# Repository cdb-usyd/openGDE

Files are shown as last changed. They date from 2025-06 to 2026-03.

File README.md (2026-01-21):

# openGDE
An open-source electrochemical test platform. Published in the Australian Journal of Chemistry. Manuscript DOI: [10.1071/CH25175](https://doi.org/10.1071/CH25175)

Repository release v1.0.0 available: 

## Information
- Designed in [openSCAD](https://openscad.org/), with code written as extensibly as possible for people to adapt for their needs.
- STLs sliced using [CURA](https://ultimaker.com/software/ultimaker-cura/) 4.12.1 or [OrcaSlicer](https://www.orcaslicer.com/) 2.3.1
- Printed on a modified Ender 3 (running [Octoprint](https://octoprint.org/) 1.9.3, all metal hot-end and glass bed for most prints).
- Printed with PLA, PETG, TPU, TPE.

## Additional hardware
- M3 nuts and bolts (12 mm).
- Standard nylon tube for pneumatic applications, 4mm OD with 2.5mm ID (cut to length and flattened with heat treatment and mold).
- Commercial membrane (tested with Nafion and Fumasep FAD)

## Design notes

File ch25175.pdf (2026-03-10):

RESEARCH PAPER

https://doi.org/10.1071/CH25175

openGDE/bayadjamara: an open-source 3D-printable gas diffusion electrochemical reactor platform

Christopher BarnettA,B,C,* | , Alexander K. L. YuenA,B | , Anthony F. MastersA | and
Thomas MaschmeyerA,B,C,*

ABSTRACT

We introduce a flexible reactor platform for testing electrocatalysts, especially for gas-phase reactants or products. This open-source, 3D-printable platform has been designed for gaseous reagents in general and is readily modified to suit a range of applications, configurations and reactor sizes. We demonstrate the versatility of our platform with iridium(IV) oxide as a standard catalyst for water splitting, using a range of conditions that relate the system’s performance to the literature. To encourage adoption of our system, we have included detailed build instructions, 3D-printing tips, example reactor configurations and a guide on modifying the provided design code. It is our hope that the simplicity, low-cost and provision of design files will encourage use of the system to more easily enable appropriate testing of gas-diffusion electrocatalysts that will allow for ready cross-laboratory comparison and benchmarking.

Keywords: 3D printing, additive manufacturing, electrocatalysis, electrochemistry, gas diffusion electrode, labware, reactor design.

Introduction
Reliable data is the cornerstone of good science. The performance of different gas diffusion electrode (GDE) catalysts must be compared using data generated from an appropriate system.¹,2 This requires well-defined electrodes and precise reactor geometry that can be easily reproduced, and most importantly, a gas diffusion setup. Despite general agreement on these requirements, the performance of catalysts proposed for use in a GDE is still mostly evaluated using standard aqueous three-electrode setups,³⁻⁵ with the gas of choice simply bubbled through the solution. There are three significant drawbacks with this approach: first, this is not a gas diffusion electrode, second, most gases have a low solubility in solution (see Solubility of Gases in Water vs. Temperature at https://www.engineeringtoolbox.com/gases-solubility-water-d_1148.html), third, the observation that often catalysts behave differently when operating in gas-in-solution systems versus pure gas or reactant-in-gas systems.¹,2,6,7
GDEs are becoming increasingly popular research platforms, with applications in: reverse fuel cells,⁶,8–13 waste remediation¹⁴ and electrolysis,¹³ as well as any electrochemical reaction where a reagent or product is a gas or is contained in a gas stream, such as CH4,

15 CO2

16–18 and CO.⁶
It has been firmly established that testing of GDE catalysts in a three-electrode setup can significantly skew the observed performance.⁶,7 The performance estimates can be skewed either too low, thereby leading to the premature exclusion of promising catalyst candidates, or too high, thereby encouraging unprofitable further research.¹,19
A case in point is that of the translation of laboratory results into commercial hydrogen fuel cells.²⁰ Even when restricting the scope to just that of platinum-based oxygen reduction reaction (ORR) catalysts, markedly different performance in liquid half-cells as compared to commercially relevant GDE-based fuel cells²¹,22 has been reported for e.g. Pt-alloys,²³ de-alloyed Pt–Ni nanoparticles¹⁹,24 and Pt–Ni nanoframes.²⁵,26 To address

For full list of author affiliations and declarations see end of paper

*Correspondence to:
Christopher Barnett
The Laboratory of Advanced Catalysis for Sustainability, The University of Sydney, Sydney, NSW, Australia
Email: christopher.barnett@sydney.edu.au

Thomas Maschmeyer
The Laboratory of Advanced Catalysis for Sustainability, The University of Sydney, Sydney, NSW, Australia
Email: thomas.maschmeyer@sydney.edu.au

Handling Editor:
Paul Bernhardt

Received: 5 November 2025
Accepted: 19 January 2026
Published: 24 February 2026

Cite this: Barnett C et al. (2026) openGDE/ bayadjamara: an open-source 3D-printable gas diffusion electrochemical reactor platform. Australian Journal of Chemistry 79, CH25175. doi:10.1071/CH25175 (https://doi.org/10.1071/CH25175)

© 2026 The Author(s) (or their employer(s)). Published by CSIRO Publishing.
This is an open access article distributed under the Creative Commons Attribution 4.0 International License (CC BY) (https://creativecommons.org/licenses/by/4.0/)

OPEN ACCESS

Downloaded from http://connectsci.au/ch/article-pdf/doi/10.1071/CH25175/1858128/ch25175.pdf by guest on 10 March 2026

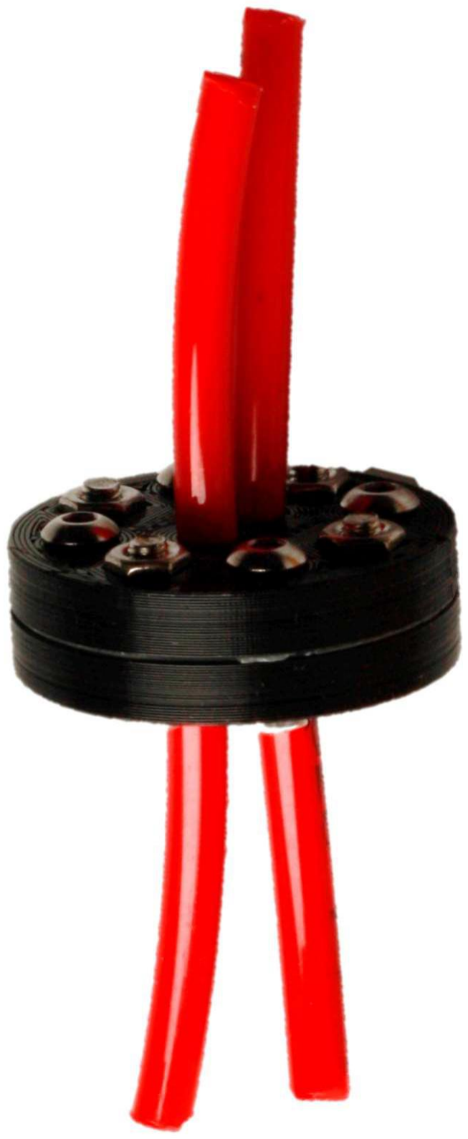
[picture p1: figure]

these inconsistencies, several calls have been made for the standardisation of candidate catalyst testing within GDE or membrane electrode assembly (MEA) setups.⁶,21,22 Although commercial GDE test reactors are available, they are expensive, non-standardised and somewhat limited in scope or adaptability. By contrast, a liquid-based three-electrode setup requires nothing more than a beaker as the reactor; though testing should ideally be performed with the working electrode (WE) and counter electrode (CE) separated, such as in U-tube cells⁴,27,28 and H-cells.²⁹ With the rise in additive manufacturing, there has been an increase in the number of reports of 3D-printed GDE reactors.¹,30,31 However, these publications often provide insufficient detail to reproduce the reactor, and we are unaware of any that provide access to the design files.
Notably, there is no agreed upon standard GDE reactor. Instead, the common practice is to compare the performance of a new catalyst against that of a ‘standard’ or benchmark catalyst, within the same reactor.³² This practice is problematic when no standard catalyst exists for a reaction, such as carbon dioxide reduction,³³ nitrogen reduction³⁴ and the dehydrogenation of ethylbenzene.³⁵ This practice also relies on reproducible benchmark catalysts to be accessible to all researchers, and for the reactor design to not mask the catalyst performance due to mass diffusion limitations or temperature gradients.³⁶
It has been elegantly shown by Ehelebe et al. that the specific GDE reactor set-up (i.e. size, shape, orientation of the gas flow field) is less important for reliable catalyst testing than reproducible sample preparation (e.g. ensuring homogeneity and representative of the bulk) and the electrochemical protocols (e.g. not diffusion limited, appropriately referenced) used.³⁷ However, these protocols rely on having a means to establish, for example, the electrochemically active surface area; a problem for newly synthesised materials or unestablished reactions. Most importantly, access to a GDE/ MEA test reactor is a pre-requisite for analysis of gas-phase electrochemistry. In these circumstances, access to a standardised reactor would allow for meaningful comparisons of catalyst performances.
To address these issues, we have developed an accessible, affordable and adaptable 3D-printed GDE/MEA test reactor: ‘openGDE’ or ‘bayadjamara’.A We provide the design files and detailed instructions on how to modify and print the reactor platform, suitable for even a relatively novice operator. 3D-printing offers adaptable design, access to unique geometries not available through traditional subtractive manufacturing, and importantly, easy fabrication of multiple reactors, which drastically lowers the cost of GDE/MEA test reactors and allows for parallel testing.
For reactions with established catalysts or electrochemical protocols,³⁷ we are confident that openGDE will facilitate comparison with existing data. This research platform is designed to encourage appropriate testing of GDE/MEA catalysts by the user community to enable and enhance research quality and outcomes, i.e. testing and comparisons of catalysts under near identical and well-specified conditions – analogous to the improvements in the field of zeolite catalysis that have arisen from the introduction of a standard, verified zeolite preparation and characterisation methods.³⁸
To achieve this end, we set out to:
1. improve the accessibility of GDE reactors for research;
2. design the GDE reactor in a way that is easily adaptable to fit a variety of needs;
3. develop a platform for 3D-printable reactors, rather than a one-off design;
4. to make printing possible on even hobbyist-grade 3D printers with readily available filaments; and
5. to simplify the design and printing process to enable confident comparisons of GDE catalysts between different laboratories.
Two configurations of our 3D-printable GDE reactor for catalyst evaluation are shown in Fig. 1 and 2, with the adaptable source files being released open-source. Both the model files (.STL and .3MF) of the components used in this work, as well as the design file (.SCAD) are available on both Github and Zenodo, which also includes instructions on how to use the ‘Customizer’ feature to modify the reactor to the required parameters (see ‘Component variables’ in the Supplementary material). Additionally, a list of common 3D-printing terminology is provided in the Table S5 of the Supplementary material.

Copper
current
collector

GDE1

GDE2

Gas

Pseudo-reference

Membrane

Gas

Gasket

Gasket

GDE chamber

Fig. 1. Left: image of example GDE|GDE reactor, using default settings (e.g. GDE 1 cm²
). Right: simplified schematic of the reactor design.

ABayadjamara means ‘air maker’ in Gadi language and has been suggested as an appropriate name by Prof. Jakelin Troy, Director, Indigenous Research, Professor of Anthropology at The University of Sydney.

C. Barnett et al. | Australian Journal of Chemistry 79 (2026) CH25175

Downloaded from http://connectsci.au/ch/article-pdf/doi/10.1071/CH25175/1858128/ch25175.pdf by guest on 10 March 2026

Experimental
Detailed printing instructions, including tips and tricks for achieving best print results, are included in the ‘3D printing instructions’, ‘3D-printing Workflow’ and ‘Specific instructions for the main components’ sections in the Supplementary material. The reactors used for this work were printed using the settings summarised in Table 1. The printing instructions included in the ‘GDE’ and ‘Aq’ setions in the Supplementary material were followed by three other researchers, who each successfully assembled openGDE. Five different printers (see ‘Printers tested’ in the Supplementary material) were also used to print operational reactors.
Bolt tightness was tested using a Vevor torque screwdriver, with the inch–pound scale converted to Newton metres. The maximum practical pressure achievable was tested using a variation of the GDE|GDE setup of openGDE. Resin held up to 4 barg, and for fused deposition modelling (FDM) between 2.5 barg (untreated) and 3.5 barg (vapour smoothed), with additional details available in the ‘Good seals’ and ‘Gasket’ sections in the Supplementary material.
To ensure consistency, multiples of each iteration of a design were printed at the one time with the same settings and filament source for each component. A bed of 16 GDE chambers on conservative print speeds is easily achieved in a single 9-h (overnight) print. The design files include the option to add a label or identifier, placed in areas that minimally affect performance, to aid in the tracking of which components were used within a given experiment.

Discussion
In 2008, the first self-replicating 3D printer, the RepRap, produced its first child printer.³⁹ This achievement, as well

GDE

Gas

Pseudo-reference

Counter electrode Aqueous chamber

Working
electrode
wire

Copper
current
collector | GDE chamber

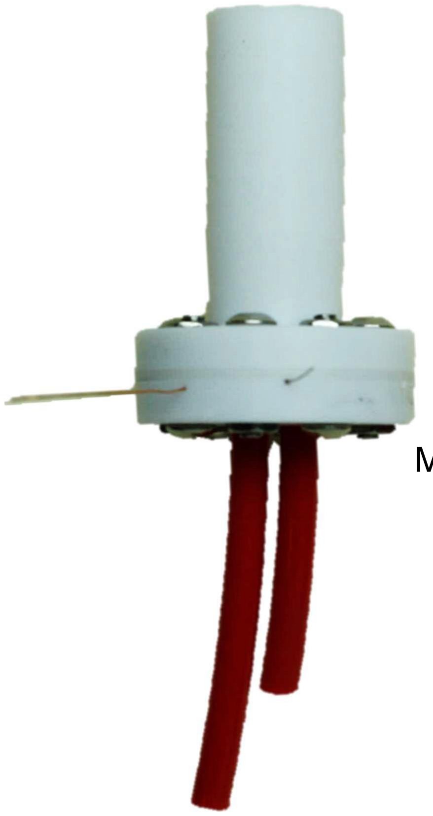
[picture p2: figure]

Membrane

Gasket

Gasket

Fig. 2. Left: image of an example GDE|Aq reactor, using default settings (e.g. GDE 1 cm²
). Right: simplified schematic of the reactor design.

Table 1. Common filament comparison.

Filament | ABS | HIPS | PETG | PLA | PP | TPE | TPU | SLA
Cost | $$ | $ | $$ | $ | $$$ | $$$ | $$ | $
Rigidity | HS | MS | HS | HS | SF | VF | F | V
Elasticity | LE | ME | M-HE | M-HE | HE | HE | HE | V
Bowden | Y | Y | Y | Y | OK | D | D | NA
H2SO4 | E | E | E | E | E | P | E | E
KOH | E | E | P | E | E | P | P | E
Na2SO4 | E | E | E | E | E | E | E | E
H2O | E | E | E | E | E | E | E | E
Nozzle (°C) | 190–210 | 230–245 | 235–245 | 210–225 | 235–245 | 235–245 | 228 | NA
Bed (°C) | 90 | 70 | 70 | 50 | 60 | NA | NA | NA A
Bed material | PEI/Glass B | PEI | Glass | Glass | PP tape | Glass | Glass | NA
Chamber | Yes | Yes | Yes | Opt. | Yes | Opt. | Opt. | Yes

Cost refers to the relative amount per kilogram from online retailers in Australia. Rigidity and Elasticity are: H (high), M (medium), L (low), S (stiff), F (flexible), E (elastic), V (varies with material. For example, SLA resins are sold with varying characteristics). The Bowden measure is whether the material is suitable to print with a Bowden extruder setup. Y (yes), OK (depends on tuning), D (difficult, not recommended for beginners). H2SO4, KOH, Na2SO4 and H2O concentrations were 0.1 M; E (excellent), P (poor) refer to how compatible the filament is with the listed solution. Bed is the recommended bed temperature during printing. Bed material is the recommended bed material. PEI (polyetherimide) and garolite are common bed materials available for purchase. Most packaging tapes are made of PP (polypropylene). Recommendations are limited to simple bed materials, not engineering grade. The Chamber measure is whether a chamber or enclosure is required for suitable prints. Opt. is optional, though a chamber is always recommended to contain the volatile components that are produced when printing. ABS, acrylonitrile butadiene styrene; HIPS, high-impact polystyrene; PETG, polyethylene terephthalate glycol; PLA, polylactic acid; TPE, thermoplastic elastomers; TPU, thermoplastic polyurethane; SLA, stereolithography. A
SLA/resin prints can fail at low ambient temperatures. B
A thin layer of ABS dissolved in acetone is applied to the surface and allowed to dry before printing.
www.publish.csiro.au/ch | Australian Journal of Chemistry 79 (2026) CH25175

Downloaded from http://connectsci.au/ch/article-pdf/doi/10.1071/CH25175/1858128/ch25175.pdf by guest on 10 March 2026 as the release of the printer designs under the free and open-source MIT license, started the additive manufacturing boom that has seen the release of hundreds of commercially available 3D printers – from DIY kits to fully assembled turnkey solutions. Over the years, through a combination of improved hardware, as well as advanced (including AIenhanced) software, the quality of printing has improved to the point of commercial products, including 3D-printed components. 3D-printing has become available to the masses, with the barrier to entry low enough that many printers are available that are plug-and-play and affordable (prices as of 6 January 2026), for example:
- US$179, Creality Ender-3 V3 SE (see https://store.creality.com/products/ender-3-v3-se-3d-printer). (https://store.creality.com/products/ender-3-v3-se-3d-printer)
- US$239, ELEGOO Neptune 4 pro (see https://us.elegoo.com/products/elegoo-neptune-4-pro-fdm-3d-printer) (https://us.elegoo.com/products/elegoo-neptune-4-pro-fdm-3d-printer)
- US$169, Anycubic Kobra 3 (see https://store.anycubic.com/products/anycubic-kobra-3). (https://store.anycubic.com/products/anycubic-kobra-3)
3D-printing has evolved beyond that of a tinkerer’s hobby – where maintenance and modification of the printer was the goal. Many 3D printers are now available as a ‘tool’, rather than a ‘project’. These printers are reliable and do not require intimate knowledge of how the machines work to achieve reliable prints. It is our hope that openGDE comes to fill the same niche, allowing researchers to 3D-print a reactor without having to delve deeply into computer aided design (CAD), while providing an open-source community to advance the platform.

Materials choice
Along with the advances in accessibility, the available materials for printing are becoming ever more numerous. Filaments are available with additives to control the printing and physical properties, as well as optional colourants added for surface finish and artistic purposes. In the context of openGDE, chemical compatibility with the solvents and reagents used is paramount. There is also the potential of contaminants in the filaments, such as metal particles,⁴⁰ or indeed constituents of the filament itself.
The final consideration is ease of printing. Although polyether ether ketone (PEEK) and polyether ketone ketone (PEKK) are both highly chemically resistant thermoplastics, they cannot be printed on a hobby 3D printer; as this requires advanced hot-ends that reach temperatures well above those achievable with such systems, and need an enclosed and actively heated chamber to avoid catastrophic warping and de-lamination. Even with these requirements met, the geometries and surface finishes achievable make it challenging to get a water-tight reactor with PEEK and PEKK.
The physical properties and chemical compatibility of several commercially available filament materials were tested for suitability for use in openGDE. The testing methodologies and details are available in the ‘Experimental details’ section of the Supplementary material, and the results are summarised in Table 1. PLA is recommended as the most suitable filament for the majority of applications due to its broad chemical resistance and ease of printing on most machines.

Dimensions and configurations of openGDE
openGDE is designed to be a testing platform, adaptable to many needs and requirements. For our experiments, we selected a GDE disc diameter of 11.2 mm, as this provides a membrane interface of 1.00 cm²
, simplifying calculations. For this size of disc, eight M3 bolts were ideal. If scaling up, larger bolts would provide a better seal; this is available in the customiser as a single bolt size variable. See the ‘Component variables’ section in the Supplementary material for more details on customising the openGDE, with examples.
There are numerous excellent papers that detail reactor configurations for various applications,³²,41,42 and an indepth discussion is beyond the scope of this paper. As well as adaptable dimensions, openGDE includes options for different configurations. Two thoroughly tested variants are discussed below.
A commonly reported setup is GDE|GDE, shown in Fig. 1, where both reactions are in the gas phase.¹,32,43 A MEA describes a membrane coated with a different catalyst on each side, and two gas flow fields.³² This MEA configuration is included in openGDE by use of a flow field insert printed from conductive filament, or a copper disc for edge contact, vide infra. However, for many GDE catalyst performance measurements, there is no need for the counter reaction to also be in the gas phase. A full GDE|GDE set-up represents an unnecessary complication when comparing GDE catalysts.²,36,37,44 We therefore designed an aqueous chamber for the counter reaction (Fig. 2). The authors are unaware of a commercial reactor that includes this set-up, could only find two examples of this concept within the literature,²,36,37 and note that no design files are provided to accompany those examples.
The openGDE aqueous chamber (Aq) is designed to provide simple assembly, with adequate access to the nuts and bolts, and the default sizing also allows for sufficient solution volume (3 mL) and membrane surface area (1 cm² ).
This setup provides reliable performance evaluation for the GDE catalyst,²,36 without the included complexity of managing two gas streams, particularly when the counter reaction has diffusion limitations or sluggish kinetics.³⁷ Complete instructions and guideline sizing limits are available in the ‘Some design choices/3D printing tricks’ and ‘Component variables’ sections of the Supplementary material.

Components of an electrochemical cell
The various methods to integrate the essential elements of an electrochemical cell into openGDE are briefly discussed here.

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

Gas flow
The default version of openGDE uses 4-mm outer diameter nylon tubing as the inlet and outlet. It was found most convenient to use a short section of tubing (5 cm) and connect to longer tubing as needed with pneumatic fittings. The tube end was heat-moulded, either against glass or a resin printed mould (see the ‘T-shaped tubes’ section in the Supplementary material for additional details).

Electrical
An electrical connection between the catalyst and the outside of the reactor was achieved by using an enamelled copper wire inserted through the reactor wall. This wire was then connected to an optional copper disc as current collector (see Fig. 3); removing the copper disc did not significantly affect the performance. Wire with a diameter of 0.2 mm was used, which has a current rating up to 200 mA, meaning that it is more than adequate for the testing included here (<10 mA).

Reference
Reference electrodes in a MEA or GDE setup are nontrivial. For our testing, we successfully implemented three set-ups:
1. The reactor can be run in symmetric mode, where the counter electrode is the reference electrode.
2. A pseudo-reference electrode is possible through insertion of either of a platinum wire or a silver-chloridecoated silver wire on the working electrode side of the membrane.
3. If the reactor is configured to include a liquid chamber, a standard reference (such as Ag/AgCl or Hg/HgO) can be used.

Membrane
Only commercial membranes have been tested in openGDE. They were sealed with the 3D-printed gasket, and the additional support provided by the bolts holds them in place.

Seals
The seals are very important to a functional reactor. Smooth mating surfaces and dimensionally matched gaskets are key for adequate sealing.

GDE/MEA
Depending on the configuration required, two methods of supporting the catalyst have been included here. The first uses a thick (0.5–2.0 mm) self-supporting carbon layer disc. The second, based on a thin gas diffusion layer (gdl), adds a flow field plate into the GDE half-reactor. The latter version is more complex, with either conductive filament or copper plating recommended for the flow field plate.

Aqueous
When using an aqueous chamber, it was found that prolonged exposure of one side of the membrane to an aqueous solution and to a comparatively dry gas on its other side could result in deformation of the membrane towards the aqueous side, eventually leading to a physical separation from the electrical contact with the GDE catalyst. A mesh

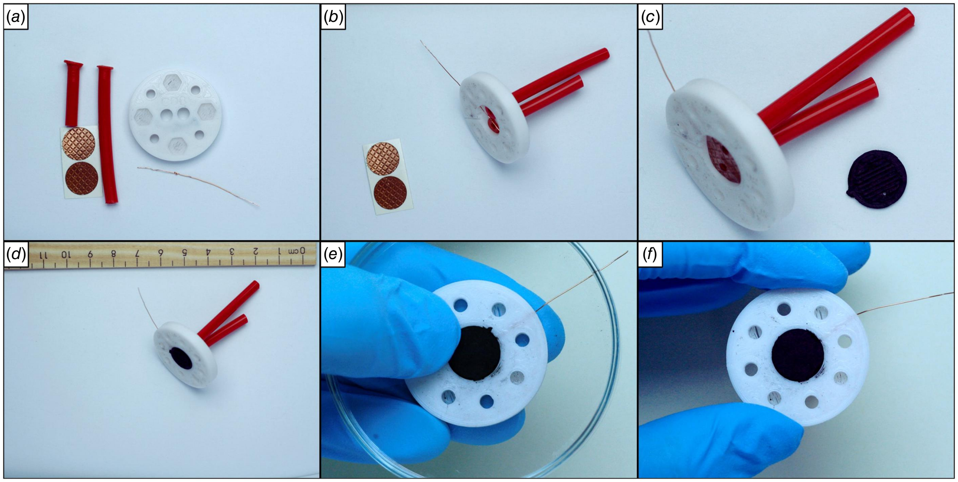
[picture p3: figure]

Fig. 3. Example assembly of a GDE sub-assembly, both the MEA and GDE versions. (a) Components needed: two T-shaped tubes, enamelled copper wire, 3D-printed GDE component (white PLA), and optional laser-cut copper tape. Not shown: gas diffusion layer (gdl) flow field insert (c, d) or GDE disc (e, f). (b) Gas tubing and enamelled wire installed. (c) Copper tape installed. Parallel flow field gdl insert shown next to component. (d) Assembled MEA half cell, with parallel gdl insert. Note the alignment pin. (e) A glass Petri dish being used to evenly insert a GDE disc into the reactor. (f) Assembled GDE sub-assembly.

Downloaded from http://connectsci.au/ch/article-pdf/doi/10.1071/CH25175/1858128/ch25175.pdf by guest on 10 March 2026 and a spacer insert were designed to hold the membrane in good contact with the GDE.

Assembly overview
The aim of openGDE is to provide an affordable and easy to construct testing platform. We therefore give a brief overview of the components needed (Fig. 4) and assembly steps involved with constructing openGDE. The Supplementary material includes more complete assembly instructions (‘Reactor assembly guides’ section), a cost breakdown (Table S3), and an example video of a reactor assembly (see CH25175_VideoS1.mkv).
The basic steps to assemble a GDE|Aq reactor are:
1. Gather M3 hardware and print the required half-reactors plus gaskets. Prepare the catalyst discs and activate chosen membrane.
2. Assemble GDE sub-assembly (Fig. 3). Insert tubing and electrical wires.
3. Prepare the gasket-membrane-gasket sandwich and pierce holes.
4. Insert catalyst disc and screw reactor together. Tighten just before use.

Electrochemistry
The capabilities of openGDE as a suitable reactor for a range of electrochemical conditions are demonstrated in Fig. 5. The experimentally simpler GDE|Aq reactor configuration was employed and printed using readily available PLA filament.
As mentioned above, there are three methods to include a reference in openGDE: (i) symmetric-mode, (ii) insertion of a pseudo-reference or (iii) use of a standard reference electrode (e.g. Ag/AgCl) in the counter reaction aqueous chamber. Each version has its advantages and disadvantages. Running a reactor in symmetric mode is commonly reported.³²,45,46 However, this requires a standardisation of the reactor using a benchmark catalyst to provide insight into the true over-potential of the reaction occurring at the working electrode. The potential of the counter reaction can vary over the course of a reaction, and the iR losses should be compensated to account for the membrane between the electrodes.³⁷ The success of the pseudo-reference method depends on the nature of the reaction taking place. Care needs to be taken to ensure that the pseudo-reference is not participating in the reaction and is not becoming fouled during the course of the experiment.⁴⁴ Finally, the use of a standard liquid reference is only possible when the counter reaction is in the liquid (using the Aq chamber); however, the iR losses still need to be considered.³⁶,37
The following dataset was collected in symmetric mode and using a known electrocatalyst (IrO2) to act as benchmark. Despite the limitations mentioned above, this is currently the literature standard for GDE reactors.³²,45,46 As shown in Fig. 5, the IrO2-free GDE performed worse for the oxygen evolution reaction (OER) and better for the hydrogen evolution reaction (HER), as expected.⁴⁵,46 However, caution should be taken when comparing data generated in this fashion, as the reference electrode, when connected to the counter electrode, must change in potential as current passes. Further discussion and sample data are available in the ‘Experimental details’ and ‘Future Work’ sections and Table S5 of the Supplementary material.
Most importantly, this method of benchmarking is only possible when a benchmark catalyst is available. openGDE enables two methods for the incorporation of a separate

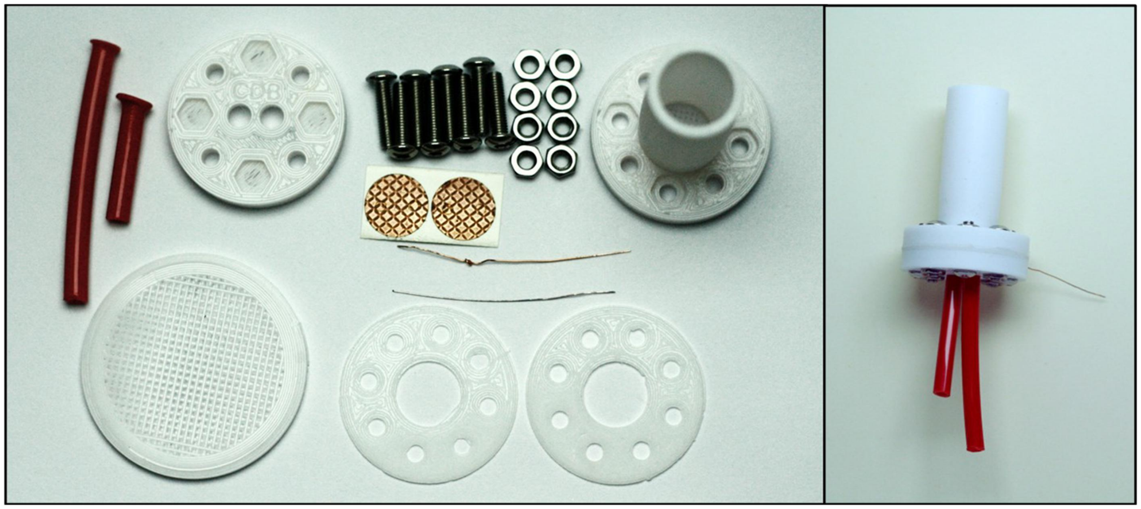
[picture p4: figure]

Fig. 4. Left: expanded view of components in a simple GDE|Aq reactor setup. Top left-to-right: Two T-shaped tubes, GDE component, eight M3 × 12 bolts, eight M3 nuts, Aq component. Middle: two copper tape discs, one enamel copper wire with knot, one Ag/AgCl wire as reference electrode. Bottom left-to-right: Membrane holder, two TPE gaskets. Right: assembled GDE|Aq reactor.

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

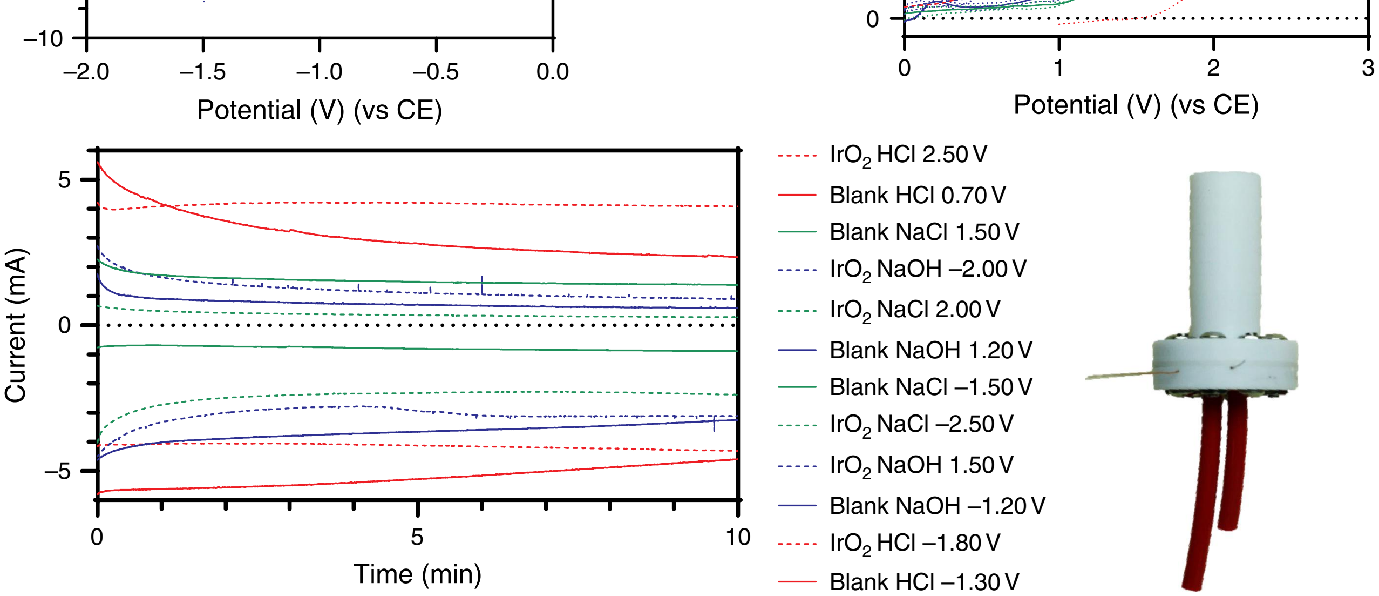
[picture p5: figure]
Time (min); Current (m; Blank HCl 0.70V; Blank HCl –1.30V; Blank NaCl 1.50V; Blank NaCl –1.50V; Blank NaOH 1.20V; Blank NaOH –1.20V; IrO2 HCl 2.50V; IrO2 HCl –1.80V; IrO2 NaCl 2.00V; IrO2 NaCl –2.50V; IrO2 NaOH 1.50V; IrO2 NaOH –2.00V; Potential (V) (vs CE)

reference electrode (pseudo- or Aq), while providing researchers with a readily accessible reactor of known geometry. This should allow suitable comparisons of electrocatalysts to be made without requiring a benchmark catalyst, particularly important when none is available.
Beyond simple water splitting, these data demonstrate that openGDE is suitable for a range of aqueous electrolytes, from highly acidic (1 M of HCl, pH = 0), to neutral (1 M of NaCl, pH = 7), to basic (1 M of NaOH, pH = 14). The reactors did not crack or leak during testing, and the self-supported catalyst discs remained intact. To test the durability, a GDE|GDE reactor made of PLA was used continuously for over 3 months without cracking or leaking. More details are available in the ‘Continuous operation tests’ section in the Supplementary material.

Conclusions
We have introduced openGDE, a design platform that is modifiable for different setups – including a gas diffusion electrode (GDE), gas diffusion layer and aqueous chamber – and demonstrated that it can produce data comparable to, or better than, reported commercial reactors.

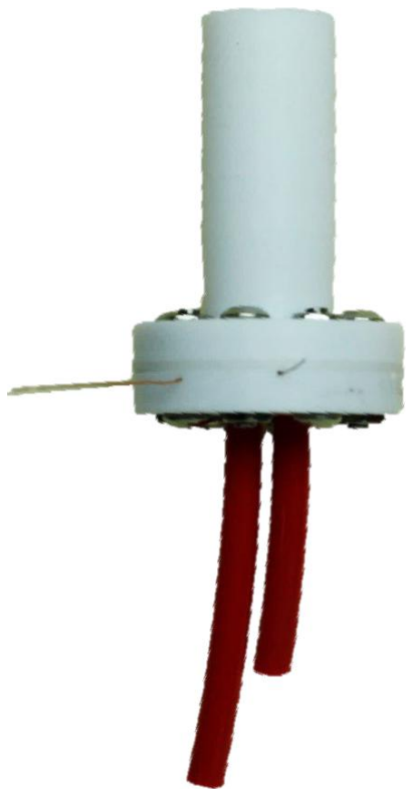
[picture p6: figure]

openGDE could represent the framework for a ‘standard’ reactor, i.e. a widely accessible reactor allowing all interested researchers access to a reliable and reproducible comparison of GDE, gdl/MEA and related catalysts. This is particularly relevant when no benchmark catalyst is available.
To our knowledge, this is the first reported 3D-printed reactor platform that provides all source files on Github and Zenodo (doi:10.5281/zenodo.18322571). (https://doi.org/10.5281/zenodo.18322571) These are provided for use and modification under an open-source license to encourage their use and adoption by the research community, no matter their previous electrochemical or 3D-printing experience. Flexibility and ease of modification, in the form of dimensions and configurations, were considered when designing the reactor platform to enable researchers to use the code without having to learn how to code themselves. As well as limiting parameters to sensible values, many print and material parameters have been tested, and best practices determined, to provide guidance on achieving reproducible results. We encourage all potential users to consider what is required for their particular research and to innovate and share accordingly.
The reactor has been tested without leaks in resin up to 4 barg and with extrusion printing between 2.5 barg (untreated) and 3.5 barg (vapour smoothed). Long-term

2

4

6

8

Current (m

A)

–5

0

Current (m

A)

IrO2 HCl
IrO2 NaCl
IrO2 NaOH
Blank HCl
Blank NaCl
Blank NaOH

Fig. 5. Example data using the GDE|Aq configuration of openGDE, demonstrating its suitability for a variety of aqueous electrolytes (red, 1 M of HCl; green, 1 M of NaCl, blue, 1 M of NaOH). All data were obtained using humidified nitrogen gas flowing through a 1-cm² GDE WE with either no additive (solid lines) or 5 wt% commercial IrO2 (dashed lines), the reference electrode (RE) = counter electrode (CE) = Pt wire in the aqueous electrolyte, and a commercial proton exchange membrane separating the two phases. Top: LSVs at 5 mV s

–1 in
duplicate for the various GDEs and electrolytes, average shown with standard deviation; left: negative potentials, hydrogen evolution reaction (HER) occurring in the working electrode (WE); right: positive potentials, oxygen evolution reaction (OER) occurring in the WE. Bottom: I–t curves at potentials as labelled.

Downloaded from http://connectsci.au/ch/article-pdf/doi/10.1071/CH25175/1858128/ch25175.pdf by guest on 10 March 2026 stability testing at electrochemically relevant conditions showed the reactor capable of continuous operation for over 90 days.
openGDE is designed to be affordable and reproducible. The cost of all parts required (even when including the printer itself and consumables) is lower than one commercial reactor of equivalent size. A generally useful benchmarking-sized reactor, consisting of a GDE|GDE setup with 1-cm² catalyst surface area, costs less than A$2 in materials to produce. We invite researchers to contact us to organise an exploratory kit provided at cost.

Supplementary material
Supplementary material is available online. Information included: design philosophy, 3D printing instructions and workflow, specific instructions for the main components, reactor assembly guides, experimental details, electrochemistry and reference electrodes, future work, 3D-printing terminology, and references. See also doi:10.5281/zenodo.18322571. (https://doi.org/10.5281/zenodo.18322571)

References
1 Browne MP, Dodwell J, Novotny F, Jaskaniec S, Shearing PR, Nicolosi V, Brett DJL, Pumera M. Oxygen evolution catalysts under proton exchange membrane conditions in a conventional three electrode cell vs. electrolyser device: a comparison study and a 3D-printed electrolyser for academic labs. J Mater Chem A 2021; 9: 9113–9123. doi:10.1039/D1TA00633A (https://doi.org/10.1039/D1TA00633A)
2 Inaba M, Jensen AW, Sievers GW, Escudero-Escribano M, Zana A, Arenz M. Benchmarking high surface area electrocatalysts in a gas diffusion electrode: measurement of oxygen reduction activities under realistic conditions. Energy Environ Sci 2018; 11: 988–994. doi:10.1039/C8EE00019K (https://doi.org/10.1039/C8EE00019K)
3 Seh ZW, Fredrickson KD, Anasori B, Kibsgaard J, Strickler AL, Lukatskaya MR, Gogotsi Y, Jaramillo TF, Vojvodic A. Twodimensional molybdenum carbide (MXene) as an efficient electrocatalyst for hydrogen evolution. ACS Energy Lett 2016; 1: 589–594. doi:10.1021/acsenergylett.6b00247 (https://doi.org/10.1021/acsenergylett.6b00247)
4 McCrory CCL, Jung S, Ferrer IM, Chatman SM, Peters JC, Jaramillo TF. Benchmarking hydrogen evolving reaction and oxygen evolving reaction electrocatalysts for solar water splitting devices. J Am Chem Soc 2015; 137: 4347–4357. doi:10.1021/ja510442p (https://doi.org/10.1021/ja510442p)
5 Zhao S, Lu X, Wang L, Gale J, Amal R. Carbon‐based metal‐free catalysts for electrocatalytic reduction of nitrogen for synthesis of ammonia at ambient conditions. Adv Mater 2019; 31: 1805367. doi:10.1002/adma.201805367 (https://doi.org/10.1002/adma.201805367)
6 Nösberger S, Du J, Quinson J, Berner E, Zana A, Wiberg GK, Arenz M. The gas diffusion electrode setup as a testing platform for evaluating fuel cell catalysts: a comparative RDE-GDE study. Electrochem Sci Adv 2023; 3: e2100190. doi:10.1002/elsa.202100190 (https://doi.org/10.1002/elsa.202100190)
7 Schröder J, Mints VA, Bornet A, Berner E, Fathi Tovini M, Quinson J, Wiberg G, Bizzotto F, El-Sayed HA, Arenz M. The gas diffusion electrode setup as straightforward testing device for proton exchange membrane water electrolyzer catalysts. JACS Au 2021; 1: 247–251. doi:10.1021/jacsau.1c00015 (https://doi.org/10.1021/jacsau.1c00015)
8 Mazúr P, Soukup J, Paidar M, Bouzek K. Gas diffusion electrodes for high temperature PEM-type fuel cells: role of a polymer binder and method of the catalyst layer deposition. J Appl Electrochem 2011; 41: 1013–1019. doi:10.1007/s10800-011-0325-9 (https://doi.org/10.1007/s10800-011-0325-9)
9 Liu Y, Tu Z, Chan SH. Performance evaluation and degradation mechanism for proton exchange membrane fuel cell with dual exhaust gas recirculation. Adv Energy Sustain Res 2023; 4: 2200180. doi:10.1002/aesr.202200180 (https://doi.org/10.1002/aesr.202200180)

10 Lim A, Kim J, Lee HJ, Kim H-J, Yoo SJ, Jang JH, Young Park H, Sung Y-E, Park HS. Low-loading IrO2 supported on Pt for catalysis of PEM water electrolysis and regenerative fuel cells. Appl Catal B: Environ 2020; 272: 118955.
11 Desmond Ng JW, Gorlin Y, Hatsukade T, Jaramillo TF. A preciousmetal-free regenerative fuel cell for storing renewable electricity. Adv Energy Mater 2013; 3: 1545–1550. doi:10.1002/aenm.201300492 (https://doi.org/10.1002/aenm.201300492) 12 Ng JWD, Tang M, Jaramillo TF. A carbon-free, precious-metal-free, high-performance O2 electrode for regenerative fuel cells and metal–air batteries. Energy Environ Sci 2014; 7: 2017–2024. doi:10.1039/C3EE44059A (https://doi.org/10.1039/C3EE44059A)
13 Yang Y, Li P, Zheng X, Sun W, Dou SX, Ma T, Pan H. Anionexchange membrane water electrolyzers and fuel cells. Chem Soc Rev 2022; 51: 9620–9693. doi:10.1039/d2cs00038e (https://doi.org/10.1039/d2cs00038e)
14 Chen L, Ding J, Zhang P, Ru Y, Wei L, Dai Q. Electro-peroxone degradation of metamitron using a gas diffusion cathode with ZIFderived heteroatom-doped porous carbon as the catalytic layer. Sep Purif Technol 2024; 342: 126923. doi:10.1016/j.seppur.2024.126923 (https://doi.org/10.1016/j.seppur.2024.126923) 15 Hibino T, Kobayashi K, Nagao M, Zhou D, Chen S, Yamamoto Y. Alternating current electrolysis for individual synthesis of methanol and ethane from methane in a thermo-electrochemical cell. ACS Catal 2023; 13: 8890–8901. doi:10.1021/acscatal.3c01333 (https://doi.org/10.1021/acscatal.3c01333)
16 Li L, Chen J, Mosali VSS, Liang Y, Bond AM, Gu Q, Zhang J. Hydrophobicity graded gas diffusion layer for stable electrochemical reduction of CO2. Angew Chem, Int Ed Engl 2022; 61: e202208534. doi:10.1002/anie.202208534 (https://doi.org/10.1002/anie.202208534)
17 Li L, Zhang X, Liu C, Mosali VSS, Chen J, Bond AM, Gu Q, Zhang J. Hydrophobicity graded gas diffusion electrode with enhanced CO intermediate coverage for high-performance electroreduction of CO2 to ethylene. Appl Catal B: Environ 2023; 331: 122597. doi:10.1016/j.apcatb.2023.122597 (https://doi.org/10.1016/j.apcatb.2023.122597)
18 Sun M, Cheng J, Yamauchi M. Gas diffusion enhanced electrode with ultrathin superhydrophobic macropore structure for acidic CO2 electroreduction. Nat Commun 2024; 15: 491. doi:10.1038/ s41467-024-44722-4 (https://doi.org/10.1038/s41467-024-44722-4)
19 Han B, Carlton CE, Kongkanand A, Kukreja RS, Theobald BR, Gan L, O’Malley R, Strasser P, Wagner FT, Shao-Horn Y. Record activity and stability of dealloyed bimetallic catalysts for proton exchange membrane fuel cells. Energy Environ Sci 2015; 8: 258–266. doi:10.1039/C4EE02144D (https://doi.org/10.1039/C4EE02144D)
20 Kodama K, Nagai T, Kuwaki A, Jinnouchi R, Morimoto Y. Challenges in applying highly active Pt-based nanostructured catalysts for oxygen reduction reactions to fuel cell vehicles. Nat Nanotechnol 2021; 16: 140–147. doi:10.1038/s41565-020-00824-w (https://doi.org/10.1038/s41565-020-00824-w) 21 Ly A, Asset T, Atanassov P. Integrating nanostructured Pt-based electrocatalysts in proton exchange membrane fuel cells. J Power Sources 2020; 478: 228516. doi:10.1016/j.jpowsour.2020.228516 (https://doi.org/10.1016/j.jpowsour.2020.228516) 22 Stephens IEL, Rossmeisl J, Chorkendorff I. Toward sustainable fuel cells. Science 2016; 354: 1378–1379. doi:10.1126/science.aal3303 (https://doi.org/10.1126/science.aal3303) 23 Pan L, Ott S, Dionigi F, Strasser P. Current challenges related to the deployment of shape-controlled Pt alloy oxygen reduction reaction nanocatalysts into low Pt-loaded cathode layers of proton exchange membrane fuel cells. Curr Opin Electrochem 2019; 18: 61–71. doi:10.1016/j.coelec.2019.10.011 (https://doi.org/10.1016/j.coelec.2019.10.011)
24 Cui C, Gan L, Heggen M, Rudi S, Strasser P. Compositional segregation in shaped Pt alloy nanoparticles and their structural behaviour during electrocatalysis. Nat Mater 2013; 12: 765–771. doi:10.1038/ nmat3668 (https://doi.org/10.1038/nmat3668)
25 Stamenkovic V. 2015 DOE Hydrogen and Fuel Cells Program Review. Nanosegregated Cathode Catalysts with Ultra-Low Platinum Loading. Project ID# FC008. Argonne National Laboratory; 2015. 001-028. Available at https://www.hydrogen.energy.gov/docs/hydrogenprogramlibraries/pdfs/review15/fc008_stamenkovic_2015_o.pdf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 (https://www.hydrogen.energy.gov/docs/hydrogenprogramlibraries/pdfs/review15/fc008_stamenkovic_2015_o.pdf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)
26 Chen C, Kang Y, Huo Z, Zhu Z, Huang W, Xin HL, Snyder JD, Li D, Herron JA, Mavrikakis M, Chi M, More KL, Li Y, Markovic NM, Somorjai GA, Yang P, Stamenkovic VR. Highly crystalline multimetallic nanoframes with three-dimensional electrocatalytic surfaces. Science 2014; 343: 1339–1343. doi:10.1126/science.1249061 (https://doi.org/10.1126/science.1249061) 27 Jung S, McCrory CCL, Ferrer IM, Peters JC, Jaramillo TF. Benchmarking nanoparticulate metal oxide electrocatalysts for the alkaline water oxidation reaction. J Mater Chem A 2016; 4: 3068–3076. doi:10.1039/C5TA07586F (https://doi.org/10.1039/C5TA07586F)

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

28 McCrory CCL, Jung S, Peters JC, Jaramillo TF. Benchmarking heterogeneous electrocatalysts for the oxygen evolution reaction. J Am Chem Soc 2013; 135: 16977–16987. doi:10.1021/ja407115p (https://doi.org/10.1021/ja407115p)
29 Zlatar M, Escalera-López D, Rodríguez MG, Hrbek T, Götz C, Mary Joy R, Savan A, Tran HP, Nong HN, Pobedinskas P, Briega-Martos V, Hutzler A, Böhm T, Haenen K, Ludwig A, Khalakhan I, Strasser P, Cherevko S. Standardizing OER electrocatalyst benchmarking in aqueous electrolytes: comprehensive guidelines for accelerated stress tests and backing electrodes. ACS Catal 2023; 13: 15375–15392. doi:10.1021/acscatal.3c03880 (https://doi.org/10.1021/acscatal.3c03880)
30 Lee C-Y, Taylor AC, Beirne S, Wallace GG. A 3D‐printed electrochemical water splitting cell. Adv Mater Technol 2019; 4: 1900433. doi:10.1002/admt.201900433 (https://doi.org/10.1002/admt.201900433)
31 Granados-Fernández R, Cárdenas-Arenas A, Montiel MA. Revolutionizing lab‐scale electrochemical reactors: innovative breakthroughs with 3D printing fabrication. ChemElectroChem 2024; 11: e202400205. doi:10.1002/celc.202400205 (https://doi.org/10.1002/celc.202400205)
32 Sapkota P, Boyer C, Dutta R, Cazorla C, Aguey-Zinsou K-F. Planar polymer electrolyte membrane fuel cells: powering portable devices from hydrogen. Sustain Energy Fuels 2020; 4: 439–468. doi:10.1039/ C9SE00861F (https://doi.org/10.1039/C9SE00861F)
33 Johnson D, Qiao Z, Djire A. Progress and challenges of carbon dioxide reduction reaction on transition metal based electrocatalysts. ACS Appl Energy Mater 2021; 4: 8661–8684. doi:10.1021/ acsaem.1c01624 (https://doi.org/10.1021/acsaem.1c01624)
34 Guo D, Wang S, Xu J, Zheng W, Wang D. Defect and interface engineering for electrochemical nitrogen reduction reaction under ambient conditions. J Energy Chem 2022; 65: 448–468. doi:10.1016/j. jechem.2021.06.012 (https://doi.org/10.1016/j.jechem.2021.06.012)
35 Gomez Sanz S, McMillan L, McGregor J, Zeitler JA, Al-Yassir N, Al-Khattaf S, Gladden LF. A new perspective on catalytic dehydrogenation of ethylbenzene: the influence of side-reactions on catalytic performance. Catal Sci Technol 2015; 5: 3782–3797. doi:10.1039/C5CY00457H (https://doi.org/10.1039/C5CY00457H)
36 Ehelebe K, Seeberger D, Paul MTY, Thiele S, Mayrhofer KJJ, Cherevko S. Evaluating electrocatalysts at relevant currents in a half-cell: the impact of Pt loading on oxygen reduction reaction. J Electrochem Soc 2019; 166: F1259. doi:10.1149/2.0911915jes (https://doi.org/10.1149/2.0911915jes)

37 Ehelebe K, Schmitt N, Sievers G, Jensen AW, Hrnji A, Collantes Jiménez P, Kaiser P, Geuß M, Ku Y-P, Jovanovi P, Mayrhofer KJJ, Etzold B, Hodnik N, Escudero-Escribano M, Arenz M, Cherevko S. Benchmarking Fuel Cell Electrocatalysts Using Gas Diffusion Electrodes: Inter-lab Comparison and Best Practices. ACS Energy Lett 2022; 7: 816–826. doi:10.1021/acsenergylett.1c02659 (https://doi.org/10.1021/acsenergylett.1c02659)
38 Robson HE, editor. Verified Syntheses of Zeolitic Materials, 2nd edn. New York, NY, USA: Elsevier; 2001.
39 Jones R, Haufe P, Sells E, Iravani P, Olliver V, Palmer C, Bowyer A. RepRap – the replicating rapid prototyper. Robotica 2011; 29: 177–191. doi:10.1017/S026357471000069X (https://doi.org/10.1017/S026357471000069X)
40 Browne MP, Pumera M. Impurities in graphene/PLA 3D-printing filaments dramatically influence the electrochemical properties of the devices. Chem Commun 2019; 55: 8374–8377. doi:10.1039/ c9cc03774h (https://doi.org/10.1039/c9cc03774h)
41 Lü X, Qu Y, Wang Y, Qin C, Liu G. A comprehensive review on hybrid power system for PEMFC-HEV: issues and strategies. Energy Convers Manag 2018; 171: 1273–1291. doi:10.1016/j.enconman.2018.06.065 (https://doi.org/10.1016/j.enconman.2018.06.065) 42 Rosli R, Sulong A, Daud W, Zulkifley M, Husaini T, Rosli M, Majlan E, Haque M. A review of high-temperature proton exchange membrane fuel cell (HT-PEMFC) system. Int J Hydrogen Energy 2017; 42: 9293–9314. doi:10.1016/j.ijhydene.2016.06.211 (https://doi.org/10.1016/j.ijhydene.2016.06.211)
43 Rabiee H, Ma B, Yang Y, Li F, Yan P, Wu Y, Zhang X, Hu S, Wang H, Ge L, Zhu Z. Advances and challenges of carbon‐free gas‐diffusion electrodes (GDEs) for electrochemical CO2 reduction. Adv Funct Mater 2025; 35: 2411195. doi:10.1002/adfm.202411195 (https://doi.org/10.1002/adfm.202411195)
44 Bard AJ, Faulkner LR. Electrochemical Methods: Fundamentals and Applications, 2nd edn. New York, NY, USA: Wiley; 2001
45 GeuÃŸ M, Milosevic M, Bierling M, Löttert L, Abbas D, Escalera-López D, Lloret V, Ehelebe K, Mayrhofer KJJ, Thiele S, Cherevko S. Investigation of iridium-based OER catalyst layers in a GDE half-cell setup: opportunities and challenges. J Electrochem Soc 2023; 170: 114510. doi:10.1149/1945-7111/ad07ac (https://doi.org/10.1149/1945-7111/ad07ac)
46 Pugliesi M, Bellini M, Pitzalis E, Poggini L, Capozzoli L, Miller HA, Evangelisti C. Low-iridium containing Ir–Ru–W nanocomposite for acidic oxygen evolution reaction: the role of tungsten on its activity and stability. ACS Appl Energy Mater 2025; 8: 8197–8206. doi:10.1021/ acsaem.5c00717 (https://doi.org/10.1021/acsaem.5c00717)

Data availability. The 3D‑printed gas diffusion electrode reactor files and firmware are archived on Zenodo (doi:10.5281/zenodo.18322571) (https://doi.org/10.5281/zenodo.18322571) with source development hosted on GitHub at https://github.com/cdb-usyd/openGDE. The version of the code employed for this study is version 1.0.0.

Conflicts of interest. The authors declare that they have no further conflicts of interest.

Declaration of funding. This work was supported by the Australian Research Council CE230100032 (to A. K. L. Yuen and C. Barnett) and DP220101511 (to A. K.
L. Yuen, T. Maschmeyer and C. Barnett).

Acknowledgements. C. Barnett, A. K. L. Yuen and T. Maschmeyer acknowledge the ARC Discovery Project DP220101511 and Sydney Nano. This work was performed on the land of the Gadigal of the Eora Nation. We thank Prof. Jakelin Troy for providing a Gadi language name for this project: bayadjamara, which means ‘air maker’. C. Barnett thanks: Dr D. Alam for advice on inlet connections, and Dr T. Hashemzadeh, Dr Y. Y. Cheng, Dr A. Katselas and Dr M. Kang for testing the 3D printing instructions for usability.

Author contributions. T. Maschmeyer initiated the research activity and aided in the discussions around design, fabrication and testing; C. Barnett jointly conceived the idea, designed, coded and printed platform, collected and analysed the data, and prepared the manuscript; A. K. L. Yuen test printed the testpiece and reproduced the reactor assembly; developed, edited and revised the manuscript; A. F. Masters provided experimental discussion and helped edit the manuscript; T. Maschmeyer revised and edited the manuscript over several iterations and helped to prepare for final submission.

Author affiliations A
The Laboratory of Advanced Catalysis for Sustainability, The University of Sydney, Sydney, NSW, Australia.

B
ARC Centre of Excellence for Carbon Science and Innovation at The University of New South Wales, Sydney, NSW, Australia.

C
Sydney Nano, The University of Sydney, Sydney, NSW, Australia.

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

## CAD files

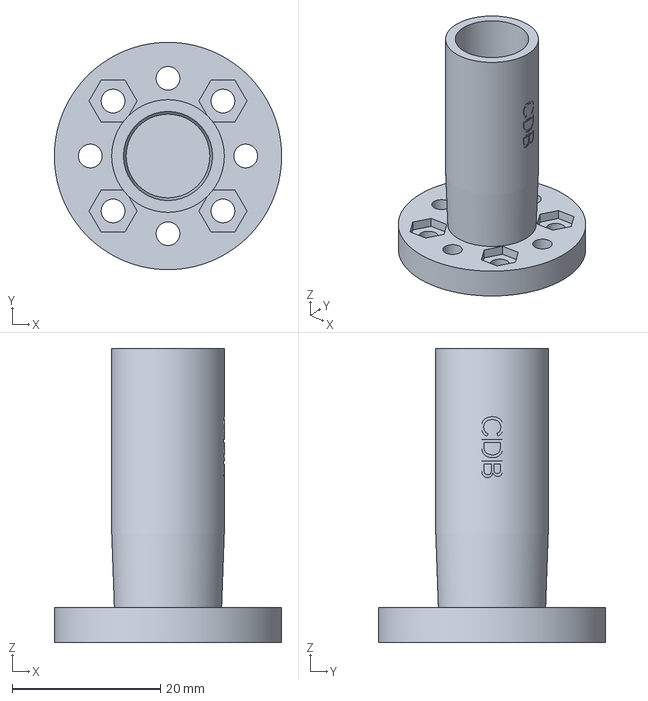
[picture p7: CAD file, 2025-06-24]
3D-print files/Aq_FDM_no-mesh.3mf
30.7 x 30.7 x 39.7 mm

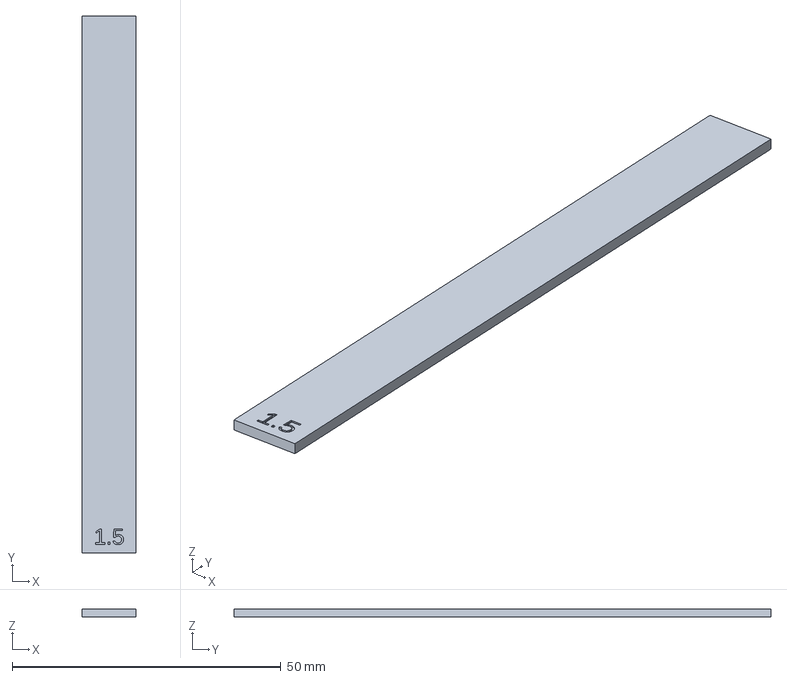
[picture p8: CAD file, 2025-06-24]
3D-print files/spacer_1-5mm.3mf
10.0 x 100.0 x 1.50 mm

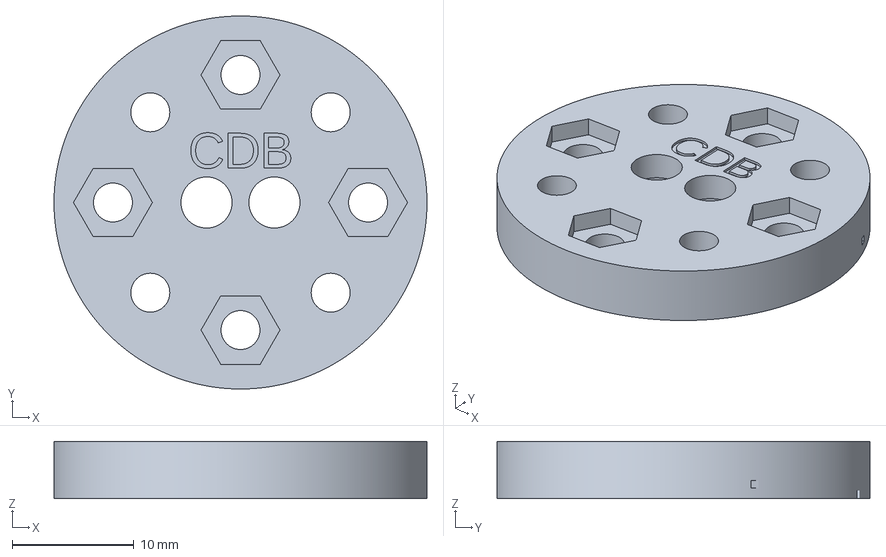
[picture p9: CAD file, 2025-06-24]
3D-print files/GDE_down_ref.3mf
30.7 x 30.7 x 4.70 mm

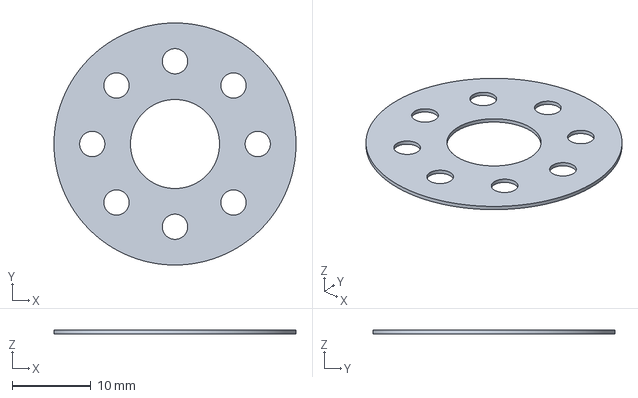
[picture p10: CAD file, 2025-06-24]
3D-print files/gasket.3mf
30.7 x 30.7 x 0.45 mm

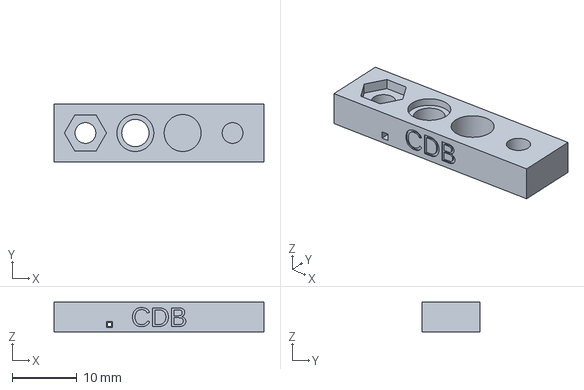
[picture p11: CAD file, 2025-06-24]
3D-print files/calibration.3mf
32.4 x 8.90 x 4.58 mm

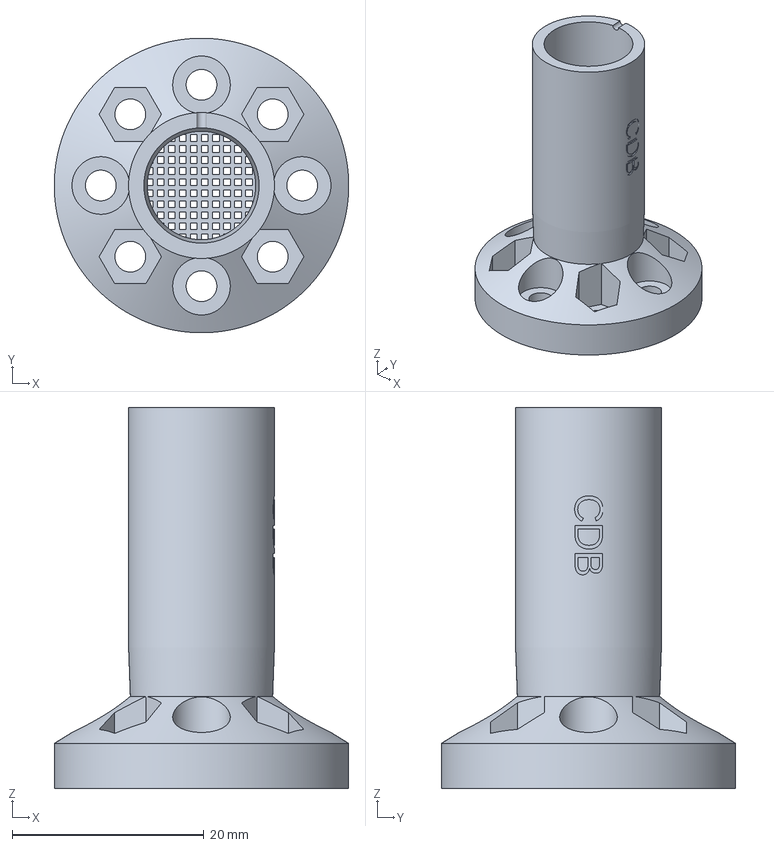
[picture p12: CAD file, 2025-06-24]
3D-print files/Aq_Resin_mesh.3mf
30.7 x 30.7 x 39.7 mm

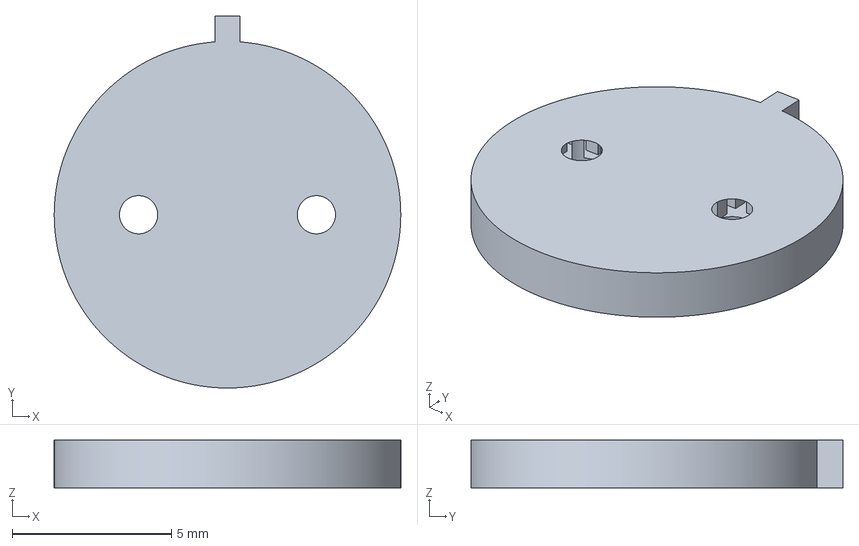
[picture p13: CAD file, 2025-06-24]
3D-print files/ff_pin.3mf
10.9 x 11.7 x 1.50 mm

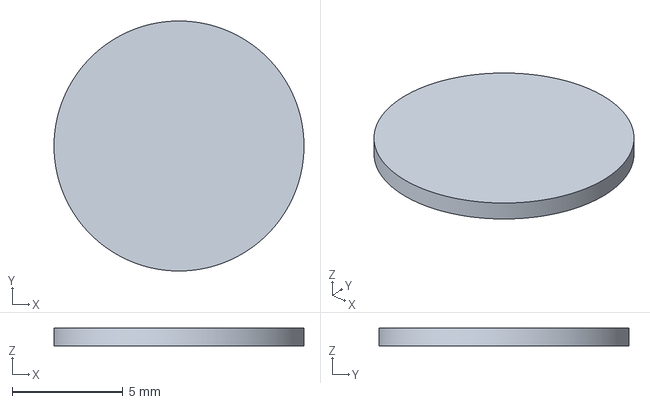
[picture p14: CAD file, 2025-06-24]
3D-print files/mesh_insert.3mf
11.3 x 11.3 x 0.8 mm

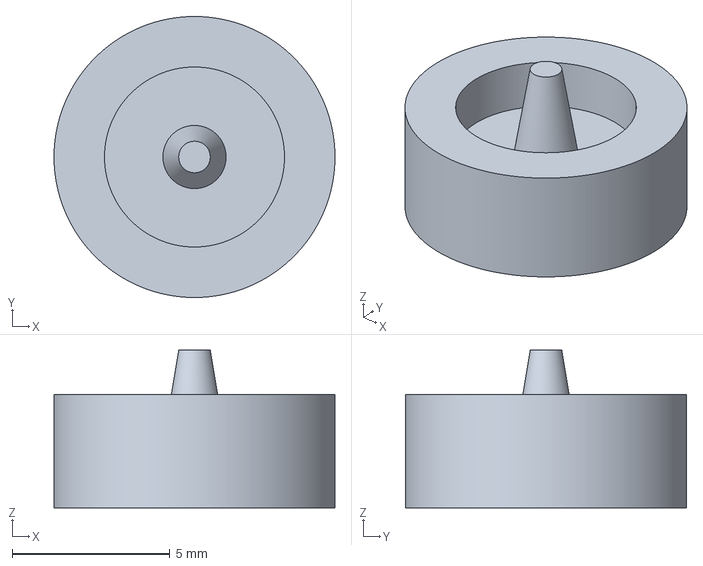
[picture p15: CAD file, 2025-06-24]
3D-print files/tube_mold.3mf
8.90 x 8.90 x 5.00 mm

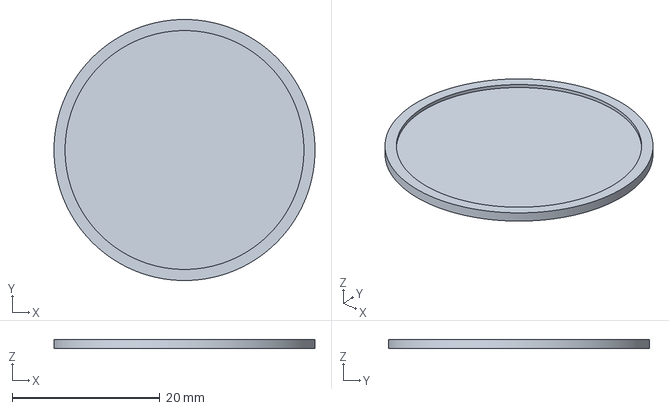
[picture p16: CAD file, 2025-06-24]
3D-print files/membrane_holder_lower.3mf
35.3 x 35.3 x 1.25 mm

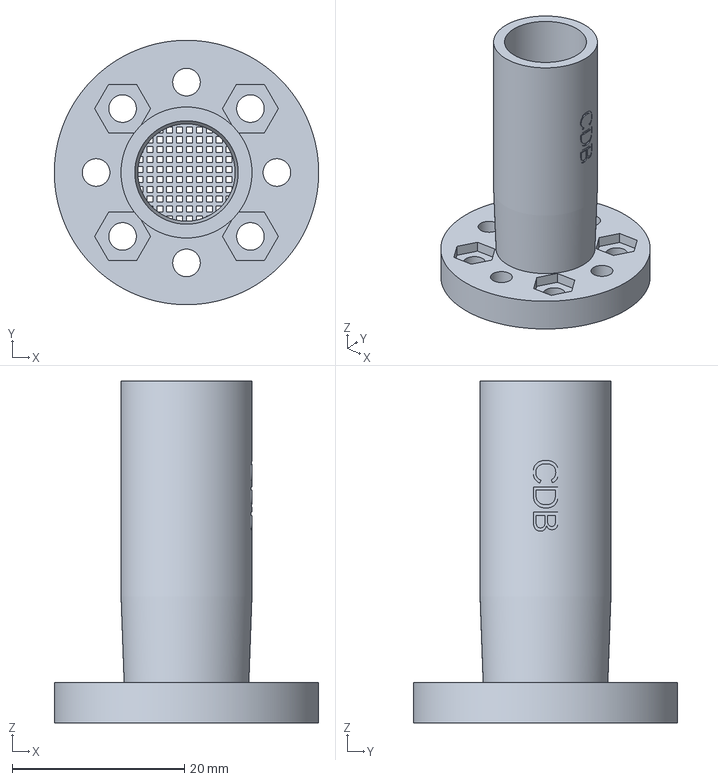
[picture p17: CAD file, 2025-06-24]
3D-print files/Aq_FDM_mesh.3mf
30.7 x 30.7 x 39.7 mm

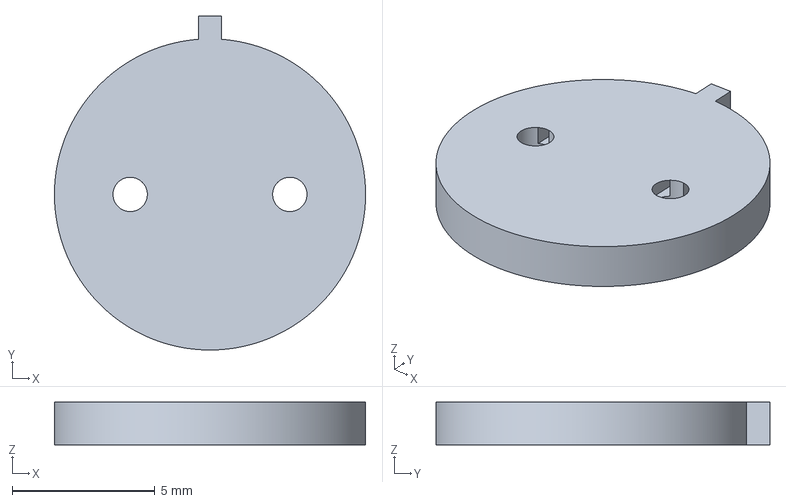
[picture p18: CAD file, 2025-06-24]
3D-print files/ff_parallel.3mf
10.9 x 11.7 x 1.50 mm

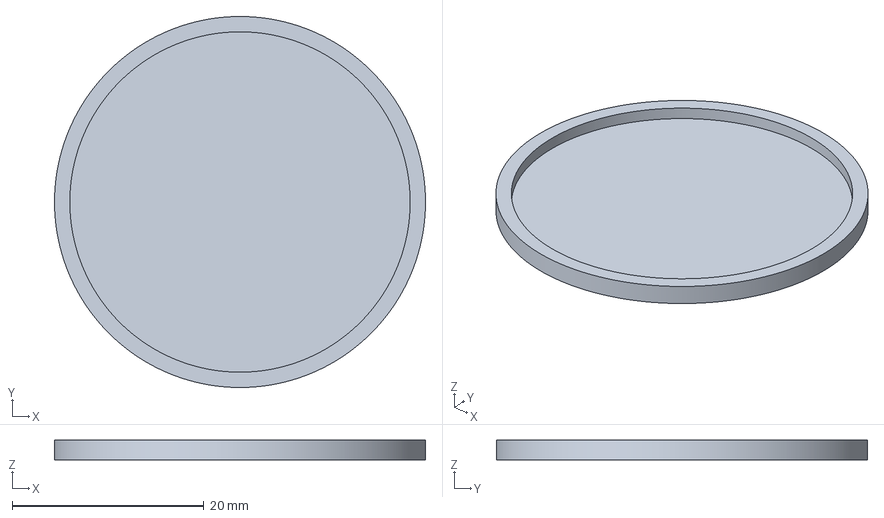
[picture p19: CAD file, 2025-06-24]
3D-print files/membrane_holder_upper.3mf
38.7 x 38.7 x 2.05 mm

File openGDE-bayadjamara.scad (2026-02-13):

//Parameters to change
/* [Component to load] */
component = "example"; // [GDE, gasket, Aq, Aq_resin, gdl_insert, membrane_holder_upper, membrane_holder_lower, mesh_insert, mesh_mod, example, calibration_piece, spacer, pressure_top, pressure_bottom,tube_mold, none]

/* [Global parameters] */
// in mm  //OD = 11.2838 is 1cm^2 area of electrode
GDE_OD = 11.2838; //[9:0.0001:50]     
// in mm //GDE cake or flow field insert thickness
GDE_H = 1.5; // [0.5:0.05:10.0]

//Add text to your printed reactor
serial = "CDB";
textsize = 3;
textdepth = 0.2; //[0.1:0.02:1.5]
//larger = smoother
$fn=100; //[10:1000]
//how many facets make up each edge (100 is usually good, larger numbers are higher resolution but take longer to load.)


//make a multiple of nozzle diameter
wall = 1.6; //four lines of 0.4 mm
bolt_d = 3.2; //m3 (calibrate)
bolt_hex_d = 6.5; //m3 (calibrate)
bolt_hex_h = 1.5;//0.8;
trapped_hex_h = 2.5; //measured height of m3 nut 2.3 mm (calibrate)
bolt_inset_h = 0.12; 
wire_d = 0.65; //0.45 too small
tubing = 4.2; //diameter of the inlet/outlet tubing (calibrate)
//the extra diameter of the flattened part of the tube
tubing_extra = 1.5;
//tube mould
tube_id = 2;
tube_od = tubing+tubing_extra;
nubbinh = 3;
base = 2;


tubing_location = (GDE_OD-tubing-tubing_extra)/2; 

///* [GDE specific variables] */

GDE_ref = true;
wire_knot = true; //insert a knotted wire from inside to outside
bridge_m3 = true;
// tick if printing on smooth glass - use support
mating_face_down = false;
// tick if using GDL insert
include_alignment_pin = false; //whether the GDE component has an alignment cutout for the GDL insert

/* [gasket variables] */
gasket_h = 0.45;
gasket_OD = GDE_OD+3*wall;
gasket_ID = GDE_OD-1*wall;

gas_chamber_h = GDE_H + 2*wall; //2 walls is a good starting point, increase if desired

/* [Aq specific variables] */
//match or make larger than GDE_OD
aqueous_chamber_d = 12; //[9:0.1:50]
//aqueous chamber height
chamber_h = 25; //[10:1:100]
chamber_transition_height = 10;
chamber_base_h = 2*wall; //2 walls is a good starting point, increase if desired
// whether you want nut recesses
aqueous_nuts = true;
// optional whether you want all nuts to have recesses
aqueous_nuts_all = false; //optional
//recommended on for resin, off for FDM (see slicer trick)
inbuilt_mesh = false;
//recommended for resin, optional for FDM
sloped_base = false;
//recommended for resin, not needed for FDM
drain_hole = false; 
//drainage hole for resin print
drain_hole_d = 1.0; // [0.1:0.1:2.0]
//Not recommended
no_base = false;



/* [gdl_insert specific variables] */
//gdl_insert flow field type
flowfieldtype = "parallel"; //[pin, parallel]
//bigger = looser
flowfield_tolerance = 0.2; //make bigger if the insert does not fit the GDE hole. Make smaller if the insert is too small

gdl_path_w = 0.4; // [0.01:0.01:8]
gdl_wall = 0.45; // [0.2:0.1:1.6]
ff_gas_inlet_d = 1.2; //the hole through which gas enters and leaves
solid_layer = 0.90; //the base of the insert, must be smaller than GDE_H-layer_height
alignment_pin = 0.8;
FF_GDE_OD = GDE_OD-2*flowfield_tolerance;
count = FF_GDE_OD/(gdl_path_w+gdl_wall);

/* [spacer parameters] */
spacer_w = 10; //[5:0.1:30]
//ensure this is smaller than your bed width
spacer_l = 100; // [40:1:300]
//This gets added to the height, a calibration workaround.
depth_offset = 0; // [-0.5:0.001:0.5]

/* [example parameter] */
cutout = false;

/* [Hidden] */
cal_d = gas_chamber_h-bolt_inset_h; 
cal_w = tubing+tubing_extra + 2*wall;
cal_l = 5*wall + 2*bolt_hex_d + 2*(tubing+tubing_extra);
//one layer for base (check either water tight or mesh slicer trick)
cal_layer = 0.2; 


mesh_h = 0.8; //the height for mesh. 0.8 mm is four layers of 0.2 mm, which seems good for strength
mesh_x = 0.7;
mesh_lw = 0.45;
resin_slope_h = 5;
m3_head = 6.0; //5.55 mm, so 6 for space.


//[GDE, Aq, Aq_resin, gasket, membrane_holder_upper, membrane_holder_lower, example]

if (component == "GDE"){
    if (mating_face_down == false){rotate([180,0,0])GDE();}else{GDE();}
    } else if (component == "gdl_insert"){
        gdl_insert();
    } else if (component == "Aq") {
        aqueous();
    } else if (component == "Aq_resin"){
        rotate([180,0,0])aqueous();
    } else if (component == "Aq_mod"){
        aq_mod();
    } else if (component == "gasket"){
        gasket();
    } else if (component == "membrane_holder_upper"){
        membrane_cage_u();
    } else if (component == "membrane_holder_lower"){
        membrane_cage_l();
    } else if (component == "mesh_insert"){
        mesh_insert();
    } else if (component == "mesh_mod"){
        mesh_mod();
    } else if (component == "example" && cutout == false){
        example();
    } else if (component == "example" && cutout == true){
        difference(){
            example();
            translate([0,-(GDE_OD+4*wall+2*bolt_hex_d)/2,0])cube([(GDE_OD+4*wall+2*bolt_hex_d)/2,GDE_OD+4*wall+2*bolt_hex_d,20]);
        }
    } else if (component == "calibration_piece"){
        calibration();
    } else if (component == "spacer"){
        spacer();
    } else if (component == "pressure_top"){
    if (mating_face_down == false){rotate([180,0,0])pressure_top();}else{pressure_top();}
    } else if (component == "pressure_bottom"){
        if (mating_face_down == false){rotate([180,0,0])pressure_bottom();}else{pressure_bottom();}
    } else if (component == "tube_mold"){
        tube_mold();
    } else if (component == "none"){
        //render nothing
    }


module calibration(){
    difference(){
        calibration_tool();
       translate([cal_l/2,textdepth,cal_d/2-textsize/2])rotate([90,0,0])linear_extrude(textdepth)text(serial,size=textsize, halign="center",valign="bottom");
    }
}

module calibration_tool(){ 
    
    difference(){
        cube([cal_l,cal_w,cal_d]);
        //m3#1
        translate([1*wall+bolt_hex_d/2,cal_w/2,0])countersunk_m3();
        //tubing
        translate([2*wall+bolt_hex_d+(tubing+tubing_extra)/2,cal_w/2,cal_d])rotate([180,0,0])countersunk_tubing_deep();
        //basin
        translate([3*wall+bolt_hex_d+tubing+tubing_extra+(tubing+tubing_extra)/2,cal_w/2,cal_layer])rotate([0,0,0])cylinder(h=cal_d-cal_layer,d=tubing+tubing_extra);
        //m3#2
        translate([4*wall+bolt_hex_d+2*(tubing+tubing_extra)+bolt_hex_d/2,cal_w/2,cal_d])rotate([0,180,0])countersunk_m3_bridged();
        //wires
        translate([wall+bolt_hex_d+wall/2,0,wall/2])rotate([0,0,90]){
            cube([cal_w,wire_d,wire_d]);
            translate([0,-wire_d/4,-wire_d/4])cube([cal_w/2,wire_d*1.5,wire_d*1.5]);}
        
    }
}

module GDE(){
    difference(){
        half_cell_gas();
        translate([0,tubing_location,gas_chamber_h-textdepth])linear_extrude(textdepth)text(serial,size=textsize,halign="center",valign="bottom");
    }
}

module pressure_top(){
    difference(){
        pressure_top_component();
        translate([0,tubing_location,gas_chamber_h-textdepth])linear_extrude(textdepth)text(serial,size=textsize,halign="center",valign="bottom");
    }
}

module pressure_bottom(){
    difference(){
        pressure_bottom_component();
        translate([0,tubing_location,gas_chamber_h-textdepth])linear_extrude(textdepth)text(serial,size=textsize,halign="center",valign="bottom");
    }
}

module aqueous(){
    difference(){
        aqueous_chamber();
        translate([aqueous_chamber_d/2+wall-textdepth,0,chamber_base_h+resin_slope_h+chamber_transition_height+chamber_h/2])rotate([0,90,0])linear_extrude(textdepth)text(serial,size=textsize,valign="center");
    }
}

module example(){

color([0,0,1])translate([0,0,15])half_cell_gas();
translate([0,0,12])gasket();
color([1,0,0])translate([0,0,10])cylinder(h=0.2, d = GDE_OD+4*wall+2*bolt_hex_d);
translate([0,0,08])gasket();
translate([0,0,5])rotate([0,180,0])half_cell_gas();
    
}

module aqueous_chamber() {
    difference(){
        union(){
            //bottom
        cylinder(h=chamber_base_h+bolt_hex_h, d = GDE_OD+2*wall);
            //slope
        translate([0,0,chamber_base_h+bolt_hex_h])cylinder(h=chamber_transition_height, d1 = GDE_OD+2*wall, d2 = aqueous_chamber_d+2*wall);
            //top
        translate([0,0,chamber_base_h+bolt_hex_h+chamber_transition_height])cylinder(h=chamber_h, d = aqueous_chamber_d+2*wall);
        }
        union(){
        //bottom
        if (no_base == true){
            cylinder(h=chamber_base_h+bolt_hex_h, d = GDE_OD);
        } else if (inbuilt_mesh == true){
            mesh();
            } else if (component == "Aq_resin"){
                mesh();
                } else {
                    translate([0,0,mesh_h])cylinder(h=chamber_base_h+bolt_hex_h-mesh_h, d = GDE_OD);
                    }
        //slope
        translate([0,0,chamber_base_h+bolt_hex_h])cylinder(h=chamber_transition_height, d1 = GDE_OD, d2 = aqueous_chamber_d);
        //top
        translate([0,0,chamber_base_h+bolt_hex_h+chamber_transition_height])cylinder(h=chamber_h, d = aqueous_chamber_d);
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

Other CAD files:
3D-print files/pressure_top.3mf
3D-print files/GDE_up_no-ref.3mf
3D-print files/GDE_down_no-ref.3mf
3D-print files/pressure_bottom.3mf
3D-print files/GDE_up_ref.3mf
3D-print files/Aq_FDM_mesh.stl
3D-print files/Aq_FDM_no-mesh.stl
3D-print files/Aq_Resin_mesh.stl
3D-print files/GDE_down_no-ref.stl
3D-print files/GDE_down_ref.stl
3D-print files/GDE_up_no-ref.stl
3D-print files/GDE_up_ref.stl
3D-print files/calibration.stl
3D-print files/ff_parallel.stl
3D-print files/ff_pin.stl
3D-print files/gasket.stl
3D-print files/membrane_holder_lower.stl
3D-print files/membrane_holder_upper.stl
3D-print files/mesh_insert.stl
3D-print files/mesh_mod.3mf
3D-print files/mesh_mod.stl
3D-print files/pressure_bottom.stl
3D-print files/pressure_top.stl
3D-print files/spacer_1-5mm.stl
3D-print files/tube_mold.stl

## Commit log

2023-10-30 Files of The Device™ for Decarbonisation event
    Example and cut out versions to show the device in GDE setup only.
    [Gas_half-cut.stl, Gas_half-cut2.stl, Gas_half.stl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]
2025-06-24 .stl and .3mf of publication components
    Files mentioned in the June version of the paper
    [Aq_FDM_mesh.3mf, Aq_FDM_mesh.stl, Aq_FDM_no-mesh.3mf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]
2026-01-09 CH25175.R1 update Add video of assembly and remove unneeded files
    [Gas_half-cut.stl, Gas_half-cut2.stl, Gas_half.stl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]
2026-02-13 SCAD file for openGDE/bayadjamara
    [openGDE-bayadjamara.scad]
2026-03-10 Add main article, and put 3D-print files into a folder
    [Aq_FDM_mesh.3mf, Aq_FDM_mesh.stl, Aq_FDM_no-mesh.3mf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]
